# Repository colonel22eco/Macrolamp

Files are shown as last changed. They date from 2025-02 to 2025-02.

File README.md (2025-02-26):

# Macrolamp

## ✨ Projektbeschreibung
Projekt zur Aufnahme von Iris Augen Fotos. Hierzu werden zwei LEDs mit einem Arduino Nano gesteuert und im Richtigen Moment ein Shutter Auslösebefehl an die angeschlossene Kamera gesendet. 
Die Helligkeit der beiden LED`s kann im Vorfeld eingestellt werden und somit eine vergrößerung der Iris bewirkt werden. Das Zeitintervall, wie lange die LEDs an bleiben ist nur durch eine Anderung des Programmcodes möglich. Die angeschlossenen LEDs sind entweder mit dem Schwarnenhals verbunden oder aber mit dem Aufsatz für das Auge. Die LEDs sind mit Kabeln und entsprechenden Steckern verbunden, so dass eine mühelose verbindung untereinander möglich ist.  

## 🛠 Installation & Einrichtung
### Voraussetzungen
- Vorderer USB geht zur Kamera
- hintere USB geht an die Stromversorgung. Entweder über ein z.B. Handynetzteil, der über eine Powerbank.

## 📝 Features
- einstellen der Helligkeit
- einfacher Wechsel der LEDs
- synchronisation des Kamerashutters mit den LEDs

## 🏆 Ziele
- Aufnahme von Irisfotos durch zeitversetztes aufnehmen von zwei Fotos. Hierdurch wird der Lichtreflex verringert.
- Zusammensetzen beider Fotos später mit Photoshop

## ⚡ Nutzung
Der Kunde Legt seinen Kopf in eine Vorrichtung zum stabilisieren des Kopfes. Anschließend wird das LED Gerät vor das Auge gehalten. Nun kann der Fotograph die LEDs in zwei Stufen einstellen. In der ersten Stufe, welche durch den druck auf den Rotary Encoder ausgeführt wird, wird die vorhelligkeit eingestellt. Bei einem weiteren Druck auf den Knopf, wird die Zielhelligkeit für die Aufnahme des Fotos eingestellt. Anschließend wird durch einen weiteren Druck auf den Encoder das Menü verlassen. Nun wird durch den Druck auf den silberen Knopf der Durchlauf gestartet. 
##   Statemachine


## 🔄 Nächste Schritte
- Testen der Hard und Software für den Ventilator
- einbinden einer Klappe im Bad, die automatisch geöffnet und geschlossen wird, basierend auf dem Zustand des Ventilators
- implementierung einer Automatischen Bewässerung basierend auf den jeweiligen Bodenfeuchtigkeitswerten
- implementierung für das Einstellen des Schwellenwertes über NodeRed für die Soll Bodenfeuchtigkeit

## 🛠 Aktuelle Probleme
- reflexion des Lichts noch schwach im Foto erkennbar. Lösung --> schwarzen dünnen Stoff oder Papier auf die LEDs kleben
- Gerät schaltet nach einigerzeit an einer Powerbank ab. Liegt aber eher an der Powerbank
- Helligkeitswerte werden aktuell im Code nur temporär, also für jeden Bootvorgang, gespeichert. Dieses kann noch so verändert werden, dass die Werte in den EEPROM geschrieben werden.

## Fotos
WhatsApp Image 2025-02-26 at 15 45 55 (2)
WhatsApp Image 2025-02-26 at 15 45 55 (1)
WhatsApp Image 2025-02-26 at 15 45 55

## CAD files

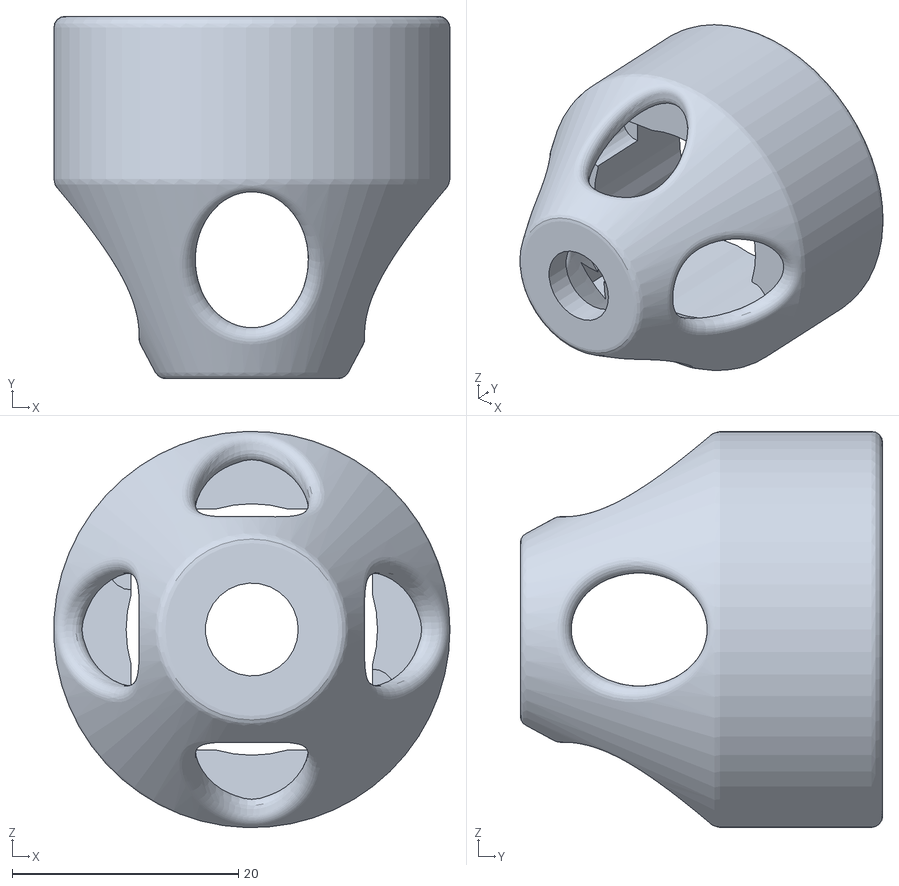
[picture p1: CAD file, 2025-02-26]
CAD/3D-Druck/LampenFront.stl
35.0 x 32.0 x 35.0

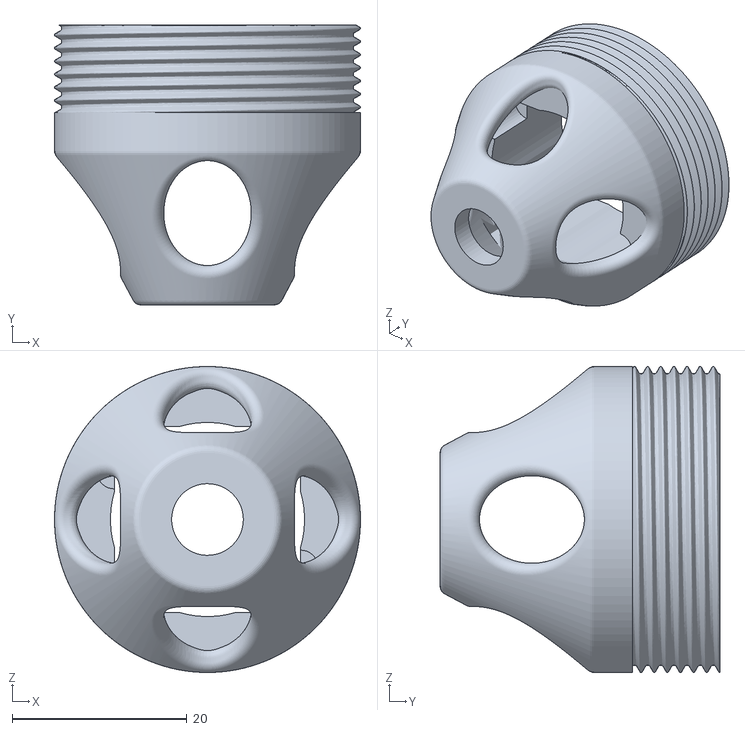
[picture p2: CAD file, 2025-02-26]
CAD/3D-Druck/Processed_LampenFront.ipt.stl
35.0 x 32.0 x 35.0

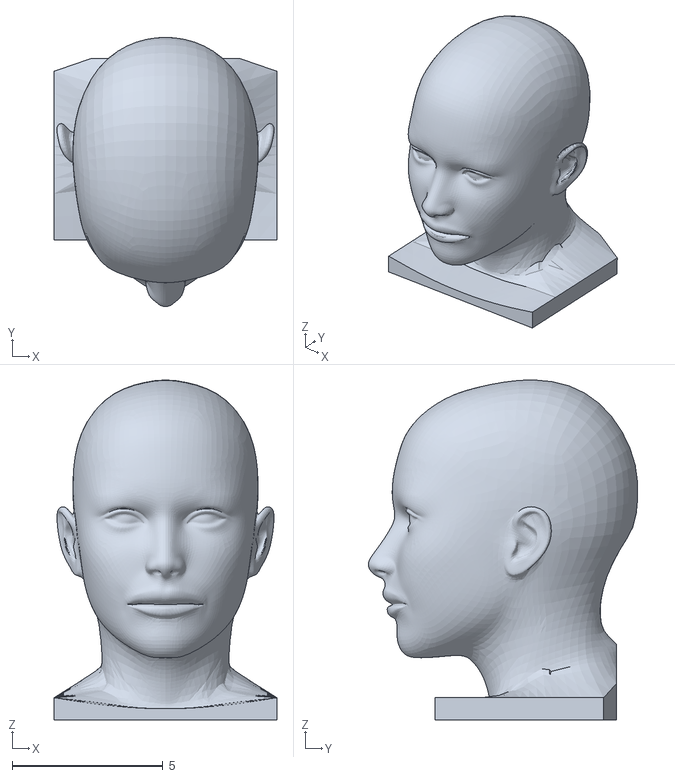
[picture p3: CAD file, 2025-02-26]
CAD/Einzelteile/HeadStand.STL
7.39 x 8.93 x 11.3

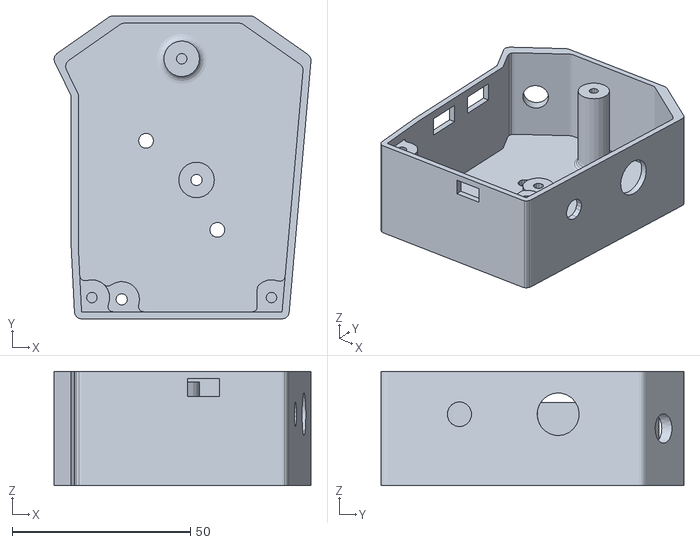
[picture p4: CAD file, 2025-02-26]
CAD/3D-Druck/Gehaueseunterteil.stl
72.1 x 85.0 x 32.0

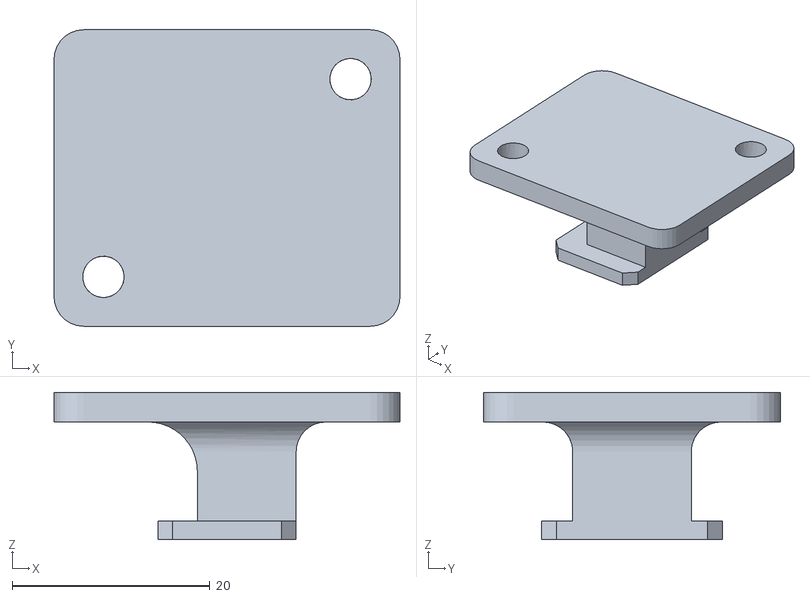
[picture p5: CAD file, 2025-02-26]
CAD/Einzelteile/hotshouh mount.stl
35.0 x 30.0 x 14.9

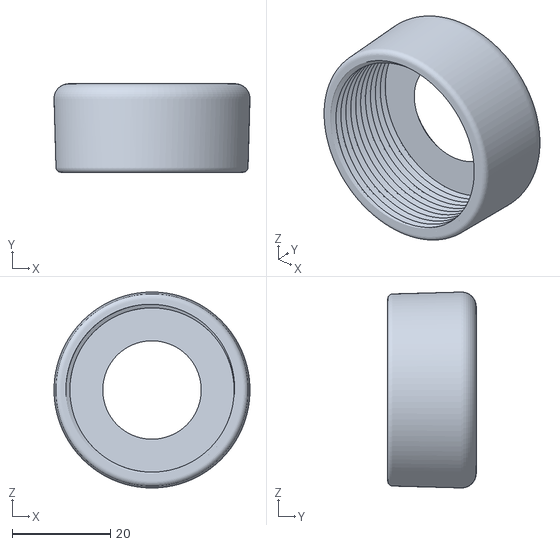
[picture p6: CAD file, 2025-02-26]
CAD/3D-Druck/Processed_Deckel.ipt.stl
39.8 x 18.0 x 39.8

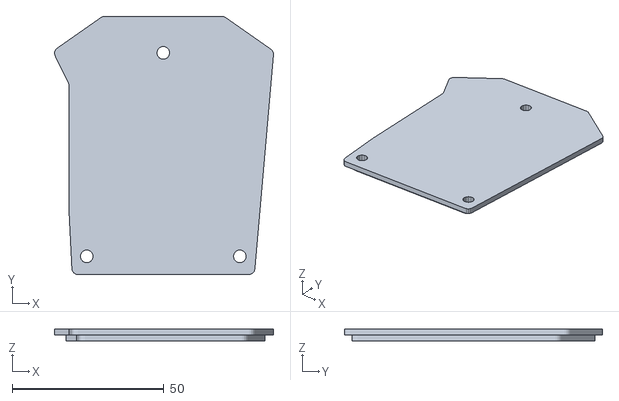
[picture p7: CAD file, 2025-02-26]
CAD/Einzelteile/Deckel_oberteil.stl
72.1 x 85.0 x 4.00

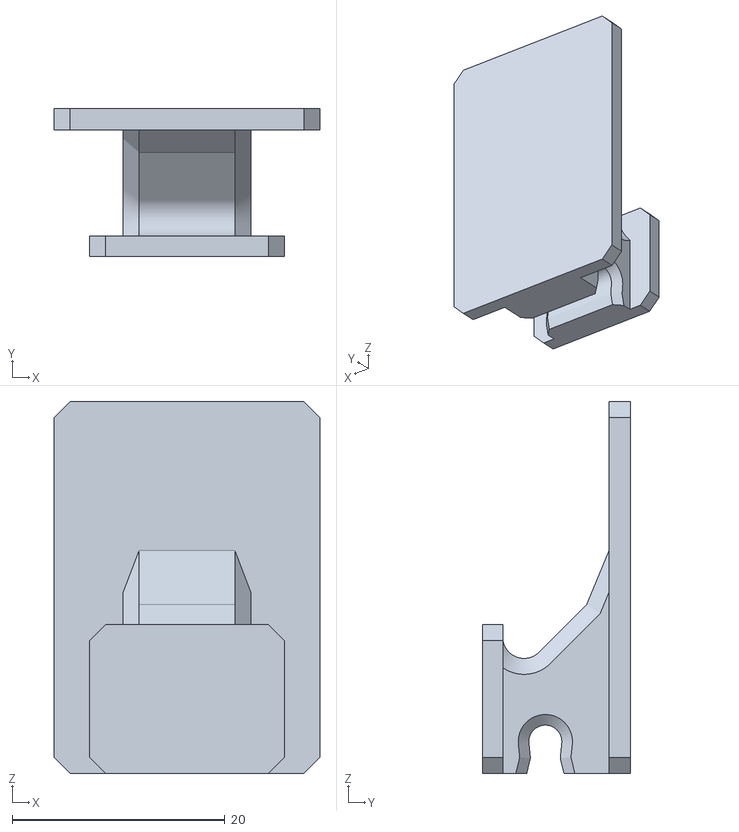
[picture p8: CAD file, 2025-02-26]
CAD/Einzelteile/SyncE-Sony.stl
25.0 x 13.9 x 35.0

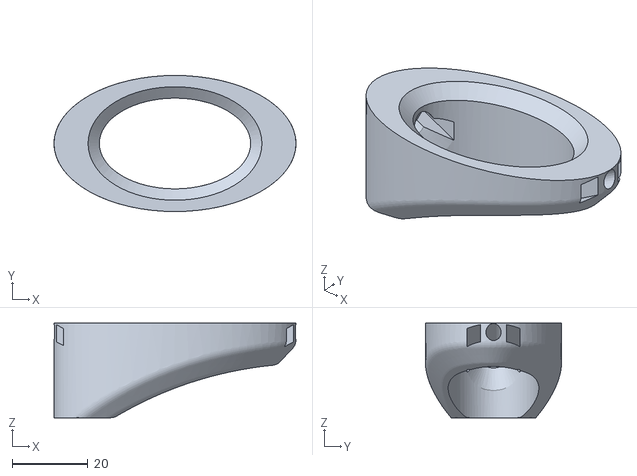
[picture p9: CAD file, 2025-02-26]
CAD/Einzelteile/RundesLicht.stl
64.0 x 36.0 x 25.0

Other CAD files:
CAD/Einzelteile/iiihead.stp
CAD/Baugruppen/Baugruppe1.iam
CAD/Baugruppen/Macrolight.iam
CAD/Baugruppen/OldVersions/Baugruppe1.0003.iam
CAD/Baugruppen/OldVersions/Macrolight.0017.iam
CAD/Einzelteile/Deckel.ipt
CAD/Einzelteile/Deckel_oberteil.ipt
CAD/Einzelteile/Gehaueseunterteil.ipt
CAD/Einzelteile/Gesichtshalter.ipt
CAD/Einzelteile/HeadStand.ipt
CAD/Einzelteile/Knopf.ipt
CAD/Einzelteile/Kühler.ipt
CAD/Einzelteile/LED-Schirm.ipt
CAD/Einzelteile/LampenFront.ipt
CAD/Einzelteile/OldVersions/Deckel.0001.ipt
CAD/Einzelteile/OldVersions/Deckel_oberteil.0002.ipt
CAD/Einzelteile/OldVersions/Gehaueseunterteil.0014.ipt
CAD/Einzelteile/OldVersions/Gesichtshalter.0001.ipt
CAD/Einzelteile/OldVersions/Kühler.0002.ipt
CAD/Einzelteile/OldVersions/LampenFront.0010.ipt
CAD/Einzelteile/OldVersions/Platine.0003.ipt
CAD/Einzelteile/OldVersions/RundesLicht.0007.ipt
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

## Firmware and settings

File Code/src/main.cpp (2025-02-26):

#include <Arduino.h>
#include <Timer.h>
#include <LED.h>
#include <Button.h>
#include <EEPROM.h>
#include <MyRotary.h> 



const int LED_1_PIN = 9;
const int LED_2_PIN = 10;
const int SHUTTER_PIN = 4;
const int BUTTON_PIN = 7;
const int BUTTON_PIN2 = 12;
const int POTI_PIN = A0;
const int ENCODER_CLK = A3;
const int ENCODER_DT = A2;

const int FOTOTIMER = 600; //min 200

// Enum für die Zustände
enum State {
  IDLE,
  LEFT_HALF_ON,
  LEFT_FULL_ON,
  RIGHT_HALF_ON,
  RIGHT_FULL_ON,
  FOTO_LEFT,
  FOTO_RIGHT, 
  ADJUST_BRIGHTNESS_LOW,
  ADJUST_BRIGHTNESS_HIGH,
  ADJUST_POSITION_LEFT,
  ADJUST_POSITION_RIGHT
};

// Variablen
State currentState = IDLE;
Timer changeTimer;
Timer rampTimer;
Led ledOne(LED_1_PIN);
Led ledTwo(LED_2_PIN);
Button b1(BUTTON_PIN);
Button b2(BUTTON_PIN2);
MyRotary rotary(ENCODER_CLK,ENCODER_DT);




bool bEntry = true;




void stateMachine();

void setup() {
  Serial.begin(9600);
  pinMode(LED_1_PIN, OUTPUT);
  pinMode(LED_2_PIN, OUTPUT);
  pinMode(SHUTTER_PIN,OUTPUT);
  pinMode(POTI_PIN,INPUT);

 
  
}

void loop() {
  //Serial.println(digitalRead(BUTTON_PIN2));
  //Serial.println(b2.getButtonClick());
  stateMachine();  
}


void stateMachine(){
  // Zustandsmaschine
  switch (currentState) {
    case IDLE:
      {if(bEntry){
        bEntry = false;
        ledOne.setBrightness(ledOne.getLowBrightness());
        ledTwo.setBrightness(ledTwo.getLowBrightness());
        //ledOne.setBrightness(10);
        //ledTwo.setBrightness(10);
        Serial.println("IDLE");
        digitalWrite(SHUTTER_PIN, LOW);
      }
 
      if (b1.getButtonClick()){
        bEntry = true;
        currentState = LEFT_HALF_ON;
      }
      if (b2.getButtonClick()){
        bEntry = true;
        currentState = ADJUST_BRIGHTNESS_LOW;
      }
      break;
      }

    case LEFT_HALF_ON:
    {if(bEntry){
        bEntry = false;
        //ledOne.ramp(ledOne.getLowBrightness(),100);
        ledOne.setBrightness(ledOne.getLowBrightness());
        ledTwo.setBrightness(0);
        changeTimer.start(2000);
        Serial.println("LEFT_HALF_ON");
      }
 
      if (changeTimer.isFinished()){
        bEntry = true;
        currentState = LEFT_FULL_ON;
      }
      break;
      }

    case LEFT_FULL_ON:
      {if(bEntry){
        bEntry = false;
        ledOne.ramp(ledOne.getHighBrightness(),600);        
        changeTimer.start(400);
        Serial.println("LEFT_FULL_ON");
      }
      if (changeTimer.isFinished()) {
        bEntry = true;
        currentState = FOTO_LEFT;
      }
      break;
      }

    case FOTO_LEFT:
      {if(bEntry){
          bEntry = false;
          digitalWrite(SHUTTER_PIN, HIGH); // Kameraauslöser aktivieren
          delay(FOTOTIMER); // Kurze Verzögerung
          digitalWrite(SHUTTER_PIN, LOW);  // Kameraauslöser deaktivieren
          
          Serial.println("FOTO_LEFT");
        }
      
      if (true) {
        bEntry = true;
        currentState = RIGHT_HALF_ON;
      }
      break;
      }

    case RIGHT_HALF_ON:
      {if(bEntry){
        bEntry = false;
        ledOne.setBrightness(0);
        ledTwo.setBrightness(ledTwo.getLowBrightness());
        //ledTwo.ramp(ledTwo.getLowBrightness(),500);
        changeTimer.start(200);
        Serial.println("RIGHT_HALF_ON");
      }
 
      if (changeTimer.isFinished()){
        bEntry = true;
        currentState = RIGHT_FULL_ON;
      }
      break;
      }

    case RIGHT_FULL_ON:
      {if(bEntry){
        bEntry = false;
        //ledTwo.ramp(ledTwo.getHighBrightness(),100);     
        ledTwo.setBrightness(ledTwo.getHighBrightness());   
        changeTimer.start(1200);
        Serial.println("RIGHT_FULL_ON");
      }
      if (changeTimer.isFinished()) {
        bEntry = true;
        currentState = FOTO_RIGHT;
      }
      break;
      }

    case FOTO_RIGHT:
      {if(bEntry){
          bEntry = false;
          digitalWrite(SHUTTER_PIN, HIGH); // Kameraauslöser aktivieren
          delay(FOTOTIMER); // Kurze Verzögerung
          digitalWrite(SHUTTER_PIN, LOW);  // Kameraauslöser deaktivieren
          Serial.println("FOTO_RIGHT");
        }
      
      if (true) {
        bEntry = true;
        currentState = IDLE;
      }
      break;
      }
    case ADJUST_BRIGHTNESS_LOW:
    {
      if(bEntry){
        bEntry = false;        
        Serial.println("ADJUST_BRIGHTNESS_LOW");
        rotary.setPosition(ledOne.getLowBrightness());
      }
      //int potiValue = map(analogRead(POTI_PIN),0,1023,0,100);
      rotary.readEncoder();
      int potiValue = rotary.getPosition();
      ledOne.setLowBrightness(potiValue);
      ledTwo.setLowBrightness(potiValue);
      ledOne.setBrightness(ledOne.getLowBrightness());
      ledTwo.setBrightness(ledTwo.getLowBrightness());
      
      if (b2.getButtonClick()){        
        bEntry = true;
        currentState = ADJUST_BRIGHTNESS_HIGH;
        
        }
      break;   
    }
    case ADJUST_BRIGHTNESS_HIGH:
    {
      if(bEntry){
        bEntry = false;        
        Serial.println("ADJUST_BRIGHTNESS_HIGH");
        rotary.setPosition(ledOne.getHighBrightness());
      }
      //int potiValue2 = map(analogRead(POTI_PIN),0,1023,0,100);
      rotary.readEncoder();
      int potiValue2 = rotary.getPosition();
      ledOne.setHighBrightness(potiValue2);
      ledTwo.setHighBrightness(potiValue2);
      ledOne.setBrightness(ledOne.getHighBrightness());
      ledTwo.setBrightness(ledTwo.getHighBrightness());
      
      if (b2.getButtonClick()){
        bEntry = true;
        currentState = ADJUST_POSITION_LEFT;
      }
      break;
    }
    case ADJUST_POSITION_LEFT:
    {
      if(bEntry){
        bEntry = false;        
        Serial.println("ADJUST_POSITION_LEFT");
      }
      
      ledOne.setBrightness(ledOne.getLowBrightness());
      ledTwo.setBrightness(0);
      
      if (b2.getButtonClick()){
        bEntry = true;
        currentState = ADJUST_POSITION_RIGHT;
      }
      break;
    }
    case ADJUST_POSITION_RIGHT:
    {
      if(bEntry){
        bEntry = false;        
        Serial.println("ADJUST_POSITION_RIGHT");
      }
      
      ledOne.setBrightness(0);
      ledTwo.setBrightness(ledTwo.getLowBrightness());
      
      if (b2.getButtonClick()){
        bEntry = true;
        currentState = IDLE;
      }
      break;
    }
  }
}
  
